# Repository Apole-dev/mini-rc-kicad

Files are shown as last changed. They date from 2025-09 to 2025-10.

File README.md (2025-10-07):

# mini-rc-kicad
## Schematic


## PCB


## 3D Modeling


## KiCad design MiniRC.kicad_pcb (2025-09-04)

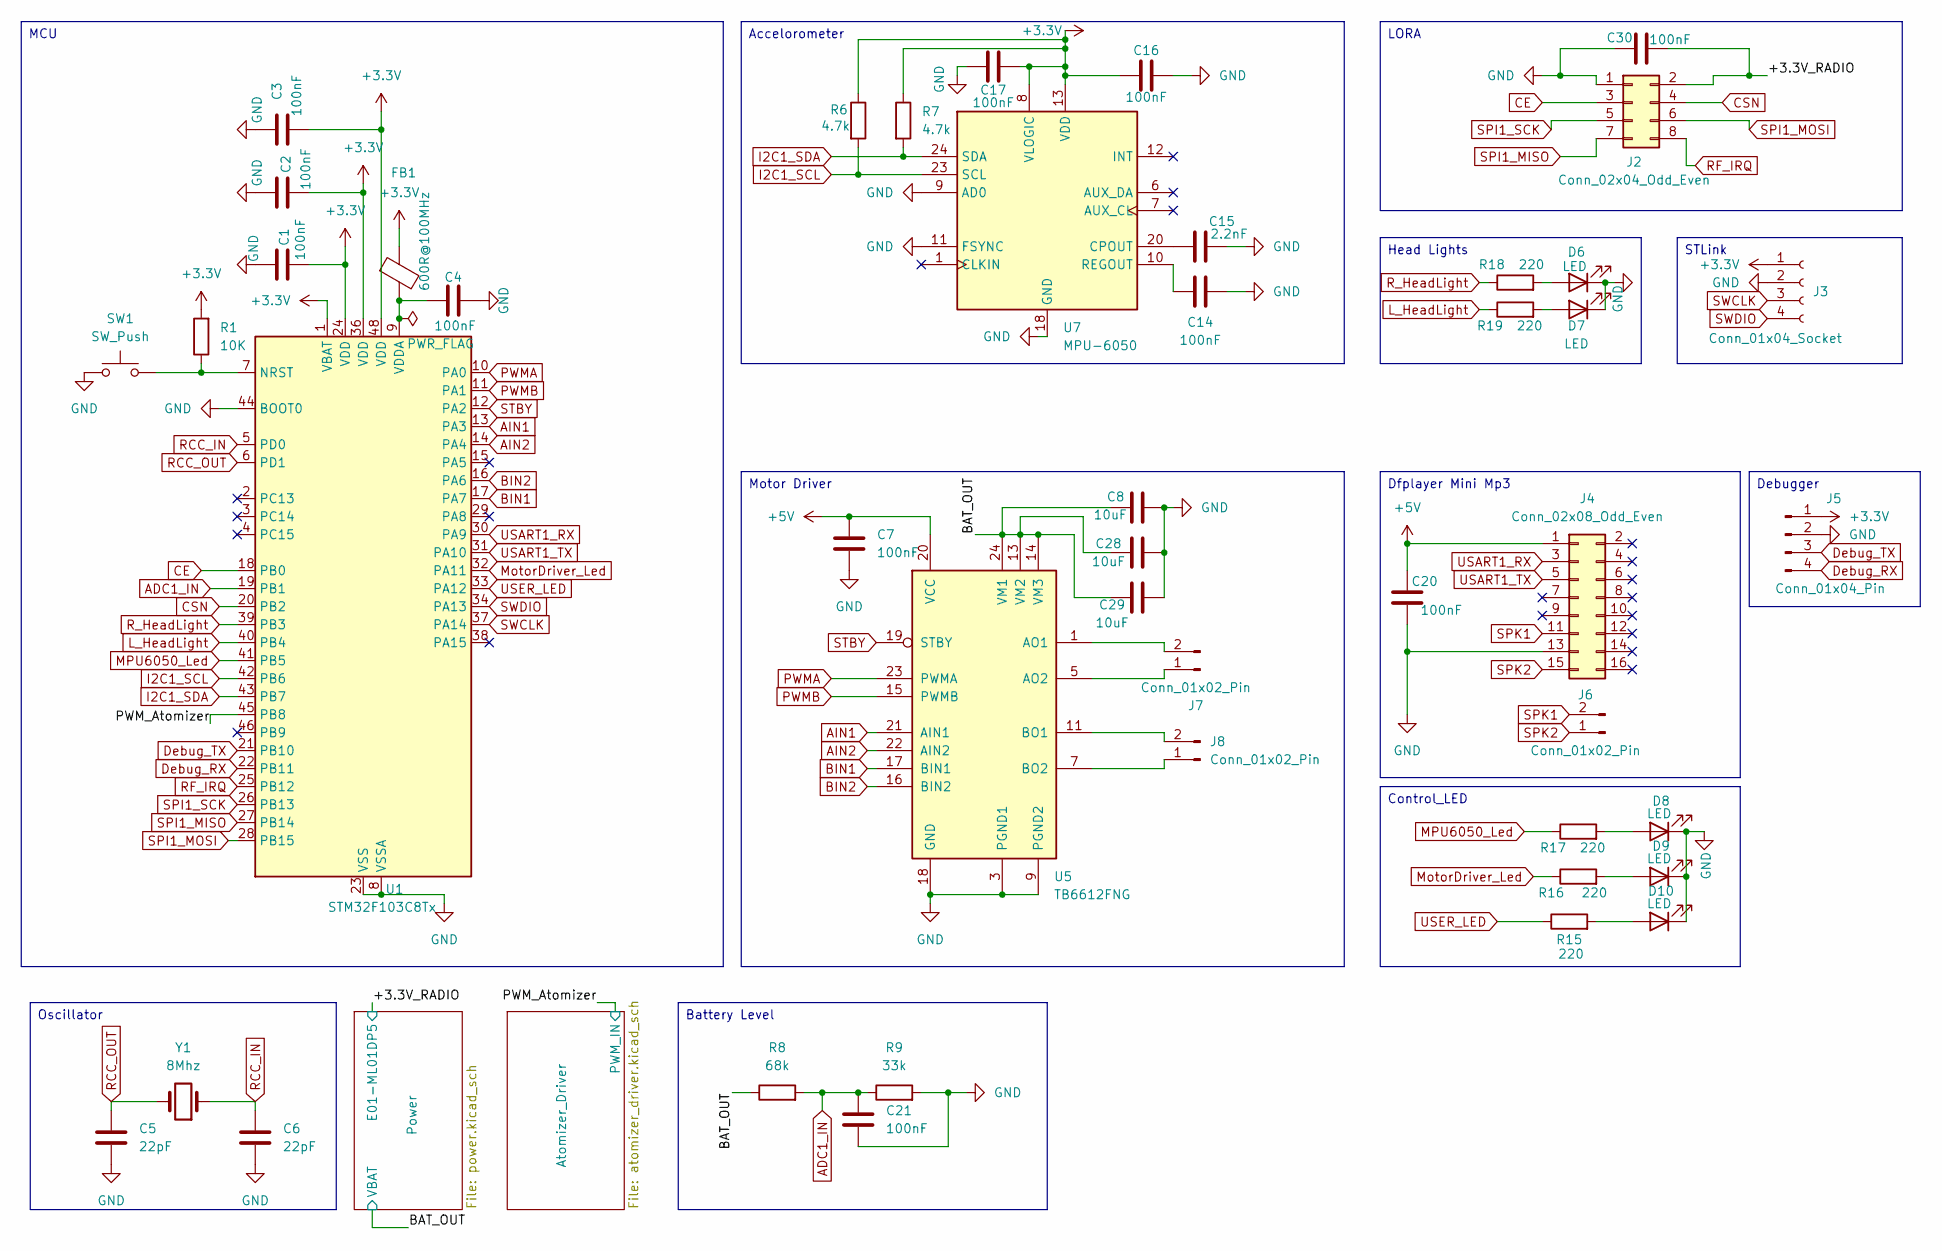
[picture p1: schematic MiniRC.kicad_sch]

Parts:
C1, C2, C3, C4, C7, C14, C16, C17, C20, C21, C30: 100nF; C_0805_2012Metric_Pad1.18x1.45mm_HandSolder
C5, C6: 22pF; C_0805_2012Metric_Pad1.18x1.45mm_HandSolder
C8, C28, C29: 10uF; C_0805_2012Metric_Pad1.18x1.45mm_HandSolder
C15: 2.2nF; C_0805_2012Metric_Pad1.18x1.45mm_HandSolder
D6, D7, D8, D9, D10: LED; LED_0805_2012Metric_Pad1.15x1.40mm_HandSolder
FB1: 600R@100MHz; R_0805_2012Metric
J2: Conn_02x04_Odd_Even; PinHeader_2x04_P2.54mm_Vertical
J3: Conn_01x04_Socket; PinHeader_1x04_P2.54mm_Vertical
J4: Conn_02x08_Odd_Even; PinHeader_2x08_P2.54mm_Vertical
J5: Conn_01x04_Pin; PinHeader_1x04_P2.54mm_Vertical
J6: Conn_01x02_Pin; SolderWire-1.5sqmm_1x02_P7.8mm_D1.7mm_OD3.9mm
J7, J8: Conn_01x02_Pin; SolderWire-0.75sqmm_1x02_P7mm_D1.25mm_OD3.5mm
R1: 10K; R_0805_2012Metric_Pad1.20x1.40mm_HandSolder
R6, R7: 4.7k; R_0805_2012Metric_Pad1.20x1.40mm_HandSolder
R8: 68k; R_0805_2012Metric_Pad1.20x1.40mm_HandSolder
R9: 33k; R_0805_2012Metric_Pad1.20x1.40mm_HandSolder
R15, R16, R17, R18, R19: 220; R_0805_2012Metric_Pad1.20x1.40mm_HandSolder
SW1: SW_Push; SW_Push_1P1T_NO_CK_KMR2
U1: STM32F103C8Tx; LQFP-48_7x7mm_P0.5mm
U5: TB6612FNG; SSOP-24_5.3x8.2mm_P0.65mm
U7: MPU-6050; InvenSense_QFN-24_4x4mm_P0.5mm
Y1: 8Mhz; Crystal_SMD_HC49-SD

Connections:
+3.3V: C1.2, C2.1, C3.2, C16.1, C17.1, FB1.1, J3.1, J5.1, R1.2, R6.1, R7.1, U1.1 (VBAT), U1.24 (VDD), U1.36 (VDD), U1.48 (VDD), U7.8 (VLOGIC), U7.13 (VDD); also elsewhere on the board
+5V: C7.1, C20.1, J4.1, U5.20 (VCC); also elsewhere on the board
/+3.3V_RADIO: C30.2, J2.2; also elsewhere on the board
/BAT_OUT: C8.1, C28.1, C29.1, R8.1, U5.13 (VM2), U5.14 (VM3), U5.24 (VM1); also elsewhere on the board
/PWM_Atomizer: U1.45 (PB8); also elsewhere on the board
ADC1_IN: C21.1, R8.2, R9.1, U1.19 (PB1)
AIN1: U1.13 (PA3), U5.21 (AIN1)
AIN2: U1.14 (PA4), U5.22 (AIN2)
BIN1: U1.17 (PA7), U5.17 (BIN1)
BIN2: U1.16 (PA6), U5.16 (BIN2)
CE: J2.3, U1.18 (PB0)
CSN: J2.4, U1.20 (PB2)
Debug_RX: J5.4, U1.22 (PB11)
Debug_TX: J5.3, U1.21 (PB10)
GND: C1.1, C2.2, C3.1, C4.2, C5.2, C6.2, C7.2, C8.2, C14.2, C15.2, C16.2, C17.2, C20.2, C21.2, C28.2, C29.2, C30.1, D6.1 (K), D7.1 (K), D8.1 (K), D9.1 (K), D10.1 (K), J2.1, J3.2, J4.13, J5.2, R9.2, SW1.1, U1.8 (VSSA), U1.23 (VSS), U1.35 (VSS), U1.44 (BOOT0), U1.47 (VSS), U5.3 (PGND1), U5.4 (PGND1), U5.9 (PGND2), U5.10 (PGND2), U5.18 (GND), U7.9 (AD0), U7.11 (FSYNC), U7.18 (GND); also elsewhere on the board
I2C1_SCL: R6.2, U1.42 (PB6), U7.23 (SCL)
I2C1_SDA: R7.2, U1.43 (PB7), U7.24 (SDA)
L_HeadLight: R19.1, U1.40 (PB4)
MPU6050_Led: R17.1, U1.41 (PB5)
MotorDriver_Led: R16.1, U1.32 (PA11)
unnamed: D6.2 (A), R18.2
unnamed: D7.2 (A), R19.2
unnamed: D8.2 (A), R17.2
unnamed: D9.2 (A), R16.2
unnamed: D10.2 (A), R15.2
unnamed: J7.1, U5.5 (AO2), U5.6 (AO2)
unnamed: J7.2, U5.1 (AO1), U5.2 (AO1)
unnamed: J8.1, U5.7 (BO2), U5.8 (BO2)
unnamed: J8.2, U5.11 (BO1), U5.12 (BO1)
unnamed: R1.1, SW1.2, U1.7 (NRST)
unnamed: C4.1, FB1.2, U1.9 (VDDA)
unnamed: C15.1, U7.20 (CPOUT)
unnamed: C14.1, U7.10 (REGOUT)
PWMA: U1.10 (PA0), U5.23 (PWMA)
PWMB: U1.11 (PA1), U5.15 (PWMB)
RCC_IN: C6.1, U1.5 (PD0), Y1.1
RCC_OUT: C5.1, U1.6 (PD1), Y1.2
RF_IRQ: J2.8, U1.25 (PB12)
R_HeadLight: R18.1, U1.39 (PB3)
SPI1_MISO: J2.7, U1.27 (PB14)
SPI1_MOSI: J2.6, U1.28 (PB15)
SPI1_SCK: J2.5, U1.26 (PB13)
SPK1: J4.11, J6.2
SPK2: J4.15, J6.1
STBY: U1.12 (PA2), U5.19 (STBY)
SWCLK: J3.3, U1.37 (PA14)
SWDIO: J3.4, U1.34 (PA13)
USART1_RX: J4.3, U1.30 (PA9)
USART1_TX: J4.5, U1.31 (PA10)
USER_LED: R15.1, U1.33 (PA12)

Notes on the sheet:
Accelorometer
Head Lights
MCU
Dfplayer Mini Mp3
Control_LED
Debugger
STLink
Oscillator
Battery Level
LORA
Motor Driver

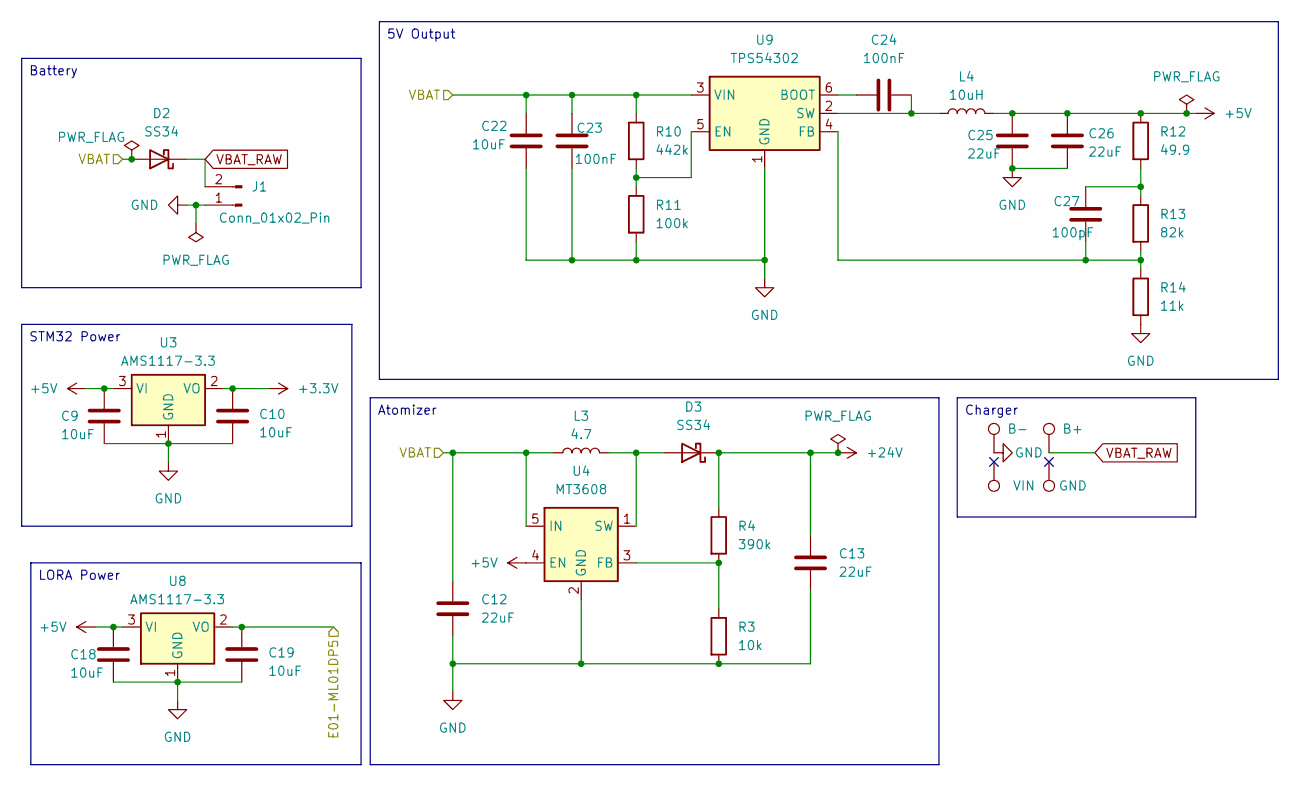
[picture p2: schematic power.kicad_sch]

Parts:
C9, C10, C18, C19, C22: 10uF; C_0805_2012Metric_Pad1.18x1.45mm_HandSolder
C12, C13, C25, C26: 22uF; C_0805_2012Metric_Pad1.18x1.45mm_HandSolder
C23, C24: 100nF; C_0805_2012Metric_Pad1.18x1.45mm_HandSolder
C27: 100pF; C_0805_2012Metric_Pad1.18x1.45mm_HandSolder
D2, D3: SS34; D_SMC_Handsoldering
J1: Conn_01x02_Pin; SolderWire-1.5sqmm_1x02_P7.8mm_D1.7mm_OD3.9mm
L3: 4.7; L_7.3x7.3_H4.5
L4: 10uH; L_7.3x7.3_H4.5
R3: 10k; R_0805_2012Metric_Pad1.20x1.40mm_HandSolder
R4: 390k; R_0805_2012Metric_Pad1.20x1.40mm_HandSolder
R10: 442k; R_0805_2012Metric_Pad1.20x1.40mm_HandSolder
R11: 100k; R_0805_2012Metric_Pad1.20x1.40mm_HandSolder
R12: 49.9; R_0805_2012Metric_Pad1.20x1.40mm_HandSolder
R13: 82k; R_0805_2012Metric_Pad1.20x1.40mm_HandSolder
R14: 11k; R_0805_2012Metric_Pad1.20x1.40mm_HandSolder
TP1: B-; TestPoint_Pad_D2.0mm
TP2: VIN; TestPoint_Pad_D2.0mm
TP3: B+; TestPoint_Pad_D2.0mm
TP4: GND; TestPoint_Pad_D2.0mm
U3, U8: AMS1117-3.3; SOT-223-3_TabPin2
U4: MT3608; SOT-23-6
U9: TPS54302; SOT-23-6

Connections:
+3.3V: C10.1, U3.2 (VO); also elsewhere on the board
+5V: C9.1, C18.1, C25.1, C26.1, L4.2, R12.1, U3.3 (VI), U4.4 (EN), U8.3 (VI); also elsewhere on the board
+24V: C13.1, D3.1 (K), R4.1; also elsewhere on the board
/+3.3V_RADIO: C19.1, U8.2 (VO); also elsewhere on the board
/BAT_OUT: C12.1, C22.1, C23.1, D2.2 (A), L3.1, R10.1, U4.5 (IN), U9.3 (VIN); also elsewhere on the board
GND: C9.2, C10.2, C12.2, C13.2, C18.2, C19.2, C22.2, C23.2, C25.2, C26.2, J1.1, R3.2, R11.2, R14.2, TP1.1, U3.1 (GND), U4.2 (GND), U8.1 (GND), U9.1 (GND); also elsewhere on the board
unnamed: C27.1, R12.2, R13.1
unnamed: D3.2 (A), L3.2, U4.1 (SW)
unnamed: R3.1, R4.2, U4.3 (FB)
unnamed: C24.2, U9.6 (BOOT)
unnamed: R10.2, R11.1, U9.5 (EN)
unnamed: C27.2, R13.2, R14.1, U9.4 (FB)
unnamed: C24.1, L4.1, U9.2 (SW)
VBAT_RAW: D2.1 (K), J1.2, TP3.1

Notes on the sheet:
5V Output
STM32 Power
Charger
Battery
LORA Power
Atomizer

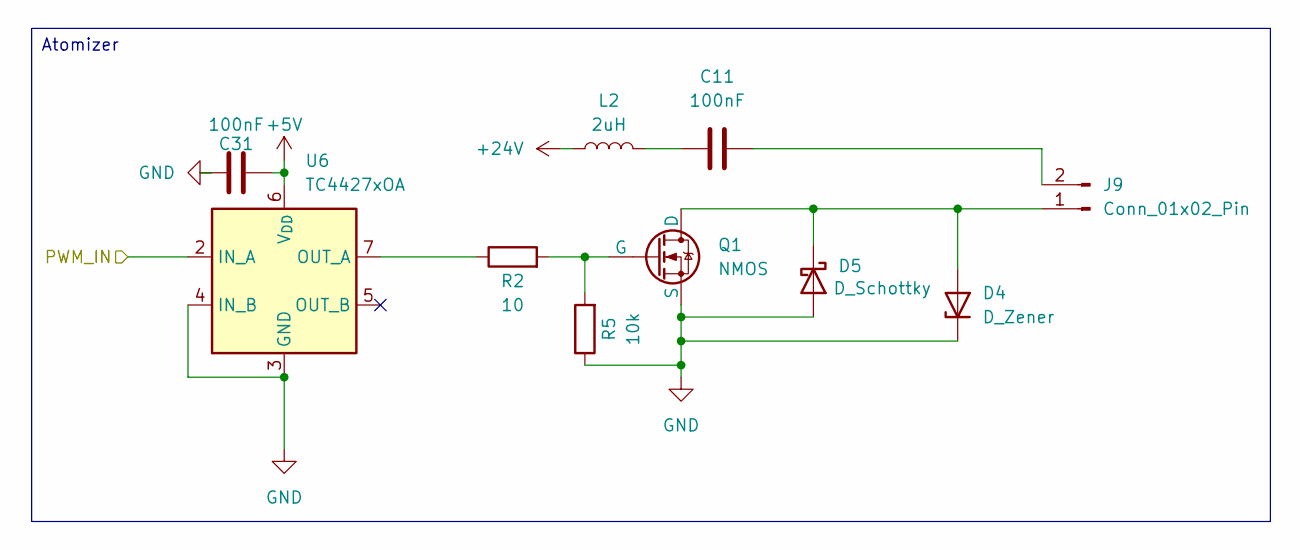
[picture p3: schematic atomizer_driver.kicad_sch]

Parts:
C11: 100nF; C_Disc_D10.5mm_W5.0mm_P10.00mm
C31: 100nF; C_0805_2012Metric_Pad1.18x1.45mm_HandSolder
D4: D_Zener; D_SMA_Handsoldering
D5: D_Schottky; D_SMA_Handsoldering
J9: Conn_01x02_Pin; SolderWire-1.5sqmm_1x02_P7.8mm_D1.7mm_OD3.9mm
L2: 2uH; L_1206_3216Metric_Pad1.22x1.90mm_HandSolder
Q1: NMOS; TO-252-2
R2: 10; R_0805_2012Metric_Pad1.20x1.40mm_HandSolder
R5: 10k; R_0805_2012Metric_Pad1.20x1.40mm_HandSolder
U6: TC4427xOA; SOIC-8_3.9x4.9mm_P1.27mm

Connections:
+5V: C31.2, U6.6 (V_{DD}); also elsewhere on the board
+24V: L2.1; also elsewhere on the board
/PWM_Atomizer: U6.2 (IN_A); also elsewhere on the board
GND: C31.1, D4.1 (K), D5.2 (A), Q1.3 (S), R5.1, U6.3 (GND), U6.4 (IN_B); also elsewhere on the board
unnamed: C11.1, L2.2
unnamed: D4.2 (A), D5.1 (K), J9.1, Q1.1 (D)
unnamed: C11.2, J9.2
unnamed: Q1.2 (G), R2.2, R5.2
unnamed: R2.1, U6.7 (OUT_A)

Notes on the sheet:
Atomizer

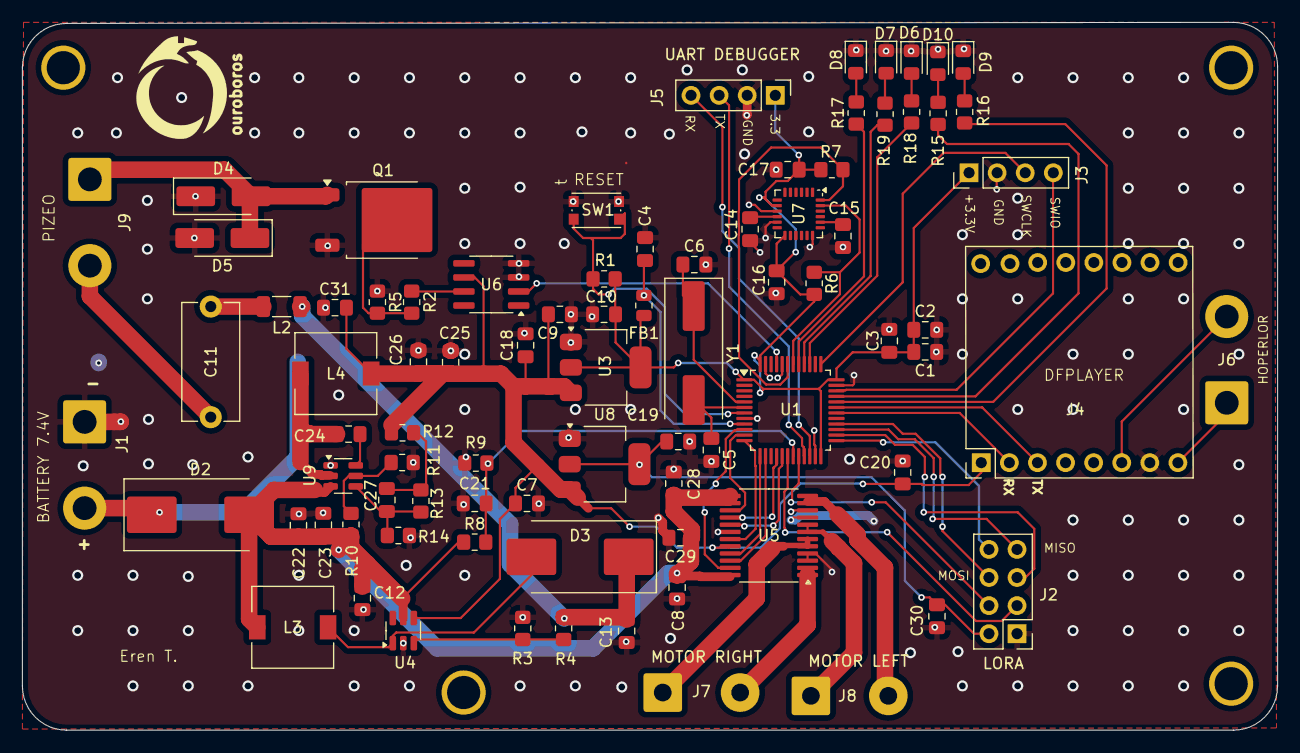
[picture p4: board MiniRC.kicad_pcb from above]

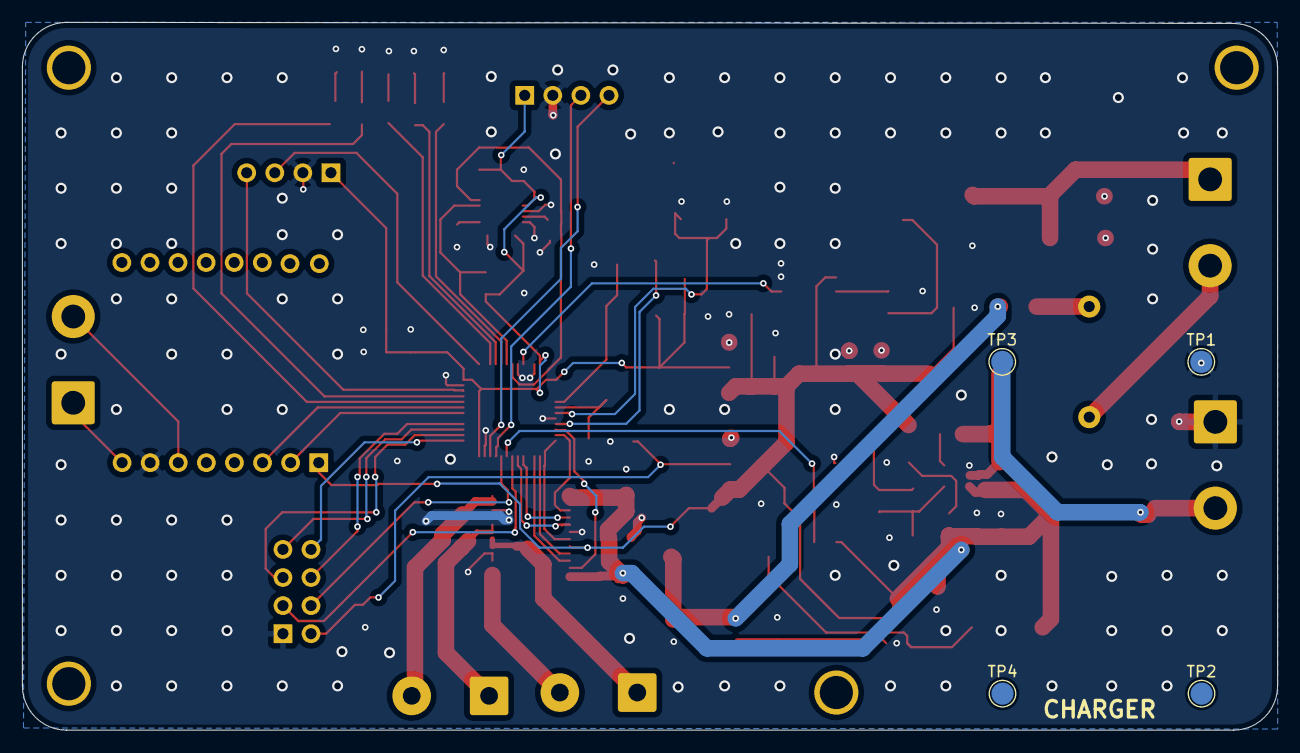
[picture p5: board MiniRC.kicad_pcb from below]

Board: 2 copper layers, 113.5 x 64.0 mm, 87 parts (4 on the bottom side), 64 nets.

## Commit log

2025-08-31 Inital Commit
    [MiniRC.kicad_pcb, MiniRC.kicad_sch, atomizer_driver.kicad_sch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]
2025-09-01 Organise details
    [MiniRC.kicad_pcb, MiniRC.kicad_sch, atomizer_driver.kicad_sch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]
